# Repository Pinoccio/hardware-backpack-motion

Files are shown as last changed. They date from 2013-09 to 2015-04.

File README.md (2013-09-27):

motino-hardware-reference
===========================

Contained are the schematics, board layout, data sheets, and BOM for the Pinoccio motion shield, containing GPS, accelerometer, digital compass, and 3-axis gyro.

The board revisions are also marked as tags in the git repository, if you'd like to see a previous version.

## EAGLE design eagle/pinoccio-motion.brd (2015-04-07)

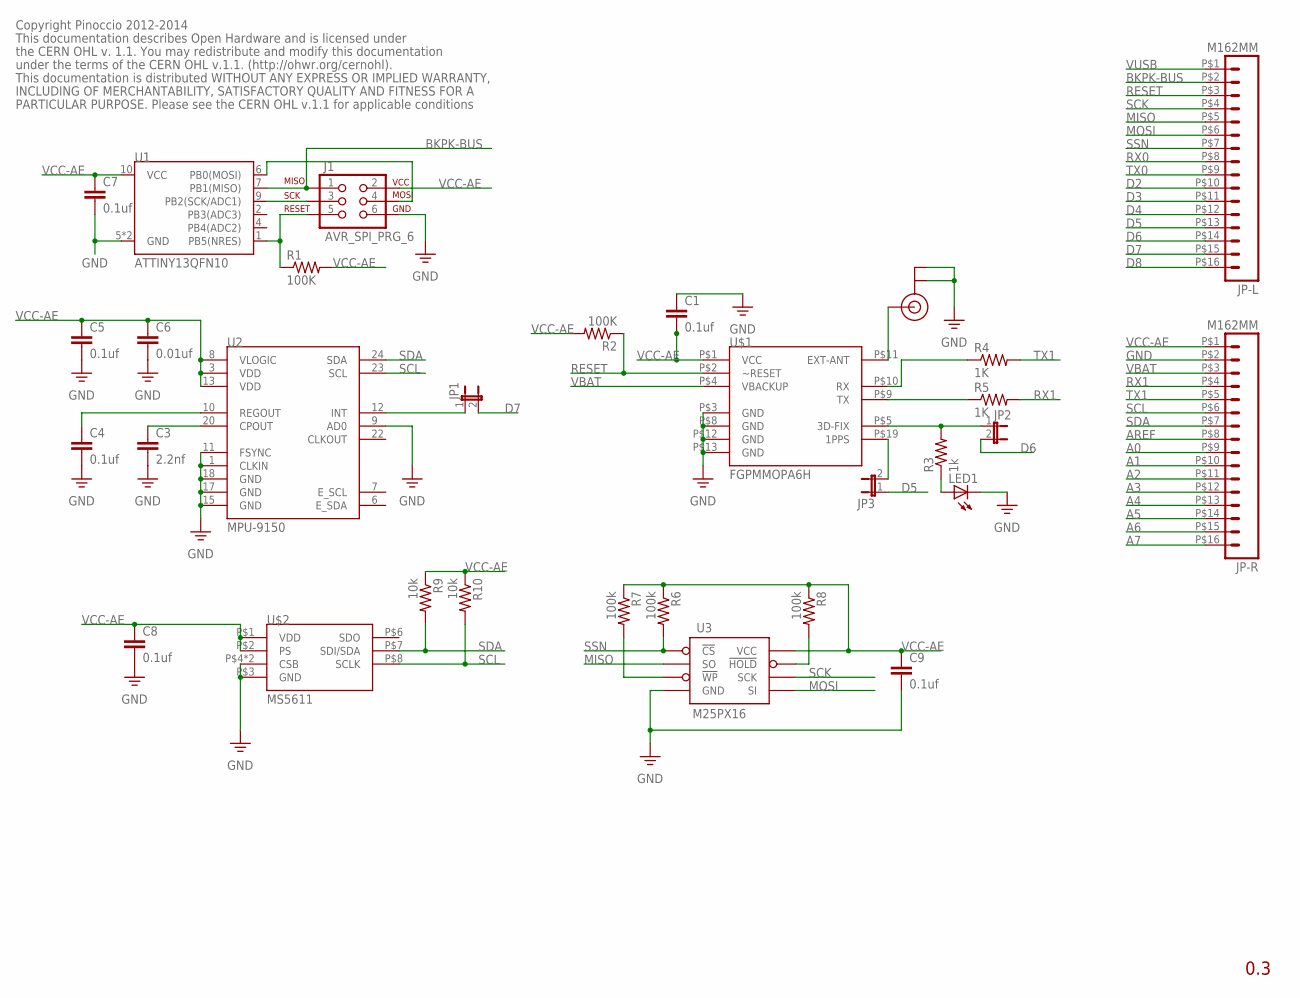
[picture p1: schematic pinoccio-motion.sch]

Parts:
C1, C4, C5, C7, C8, C9: 0.1uf; 0402-CAP
C3: 2.2nf; 0603-CAP
C6: 0.01uf; 0402-CAP
J1: AVR_SPI_PRG_6; 2X3-PAD
JP1, JP2, JP3: JUMPER-2SMD-NC; SJ_2S
JP-L: M162MM; 1X16_2MM
JP-R: M162MM; 1X16_2MM
LED1: LED0603; LED-0603
R1, R2: 100K; 0402-RES
R3: 1k; 0402-RES
R4, R5: 1K; 0402-RES
R6, R7, R8: 100k; 0402-RES
R9, R10: 10k; 0402-RES
U1: ATTINY13QFN10; QFN-10
U2: MPU-9150; QFN-24-NP
U3: M25PX16; SO8N
U$1: FGPMMOPA6H
U$2: MS5611
U$4: U.FL

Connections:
A0: JP-R.P$9 (9)
A1: JP-R.P$10 (10)
A2: JP-R.P$11 (11)
A3: JP-R.P$12 (12)
A4: JP-R.P$13 (13)
A5: JP-R.P$14 (14)
A6: JP-R.P$15 (15)
A7: JP-R.P$16 (16)
AREF: JP-R.P$8 (8)
BKPK-BUS: J1.1, JP-L.P$2 (2), U1.7 (PB1(MISO))
D2: JP-L.P$10 (10)
D3: JP-L.P$11 (11)
D4: JP-L.P$12 (12)
D5: JP3.1, JP-L.P$13 (13)
D6: JP2.2, JP-L.P$14 (14)
D7: JP1.2, JP-L.P$15 (15)
D8: JP-L.P$16 (16)
GND: C1.1, C3.2, C4.2, C5.2, C6.2, C7.2, C8.2, C9.2, J1.6, JP-R.P$2 (2), LED1.C, U1.5 (GND), U1.EP (GND), U2.1 (CLKIN), U2.9 (AD0), U2.11 (FSYNC), U2.15 (GND), U2.17 (GND), U2.18 (GND), U3.4 (GND), U$1.P$3 (GND), U$1.P$8 (GND), U$1.P$12 (GND), U$1.P$13 (GND), U$2.P$3 (GND), U$2.P$4 (CSB), U$2.P$5 (CSB), U$4.P$1 (GND), U$4.P$2 (GND)
MISO: JP-L.P$5 (5), U3.2 (SO)
MOSI: JP-L.P$6 (6), U3.5 (SI)
unnamed: J1.4, U1.6 (PB0(MOSI))
unnamed: R4.1, U$1.P$10 (RX)
unnamed: J1.3, U1.9 (PB2(SCK/ADC1))
unnamed: J1.5, R1.1, U1.1 (PB5(NRES))
unnamed: U$1.P$11 (EXT-ANT), U$4.P$3 (SIGNAL)
unnamed: R5.1, U$1.P$9 (TX)
unnamed: JP1.1, U2.12 (INT)
unnamed: C3.1, U2.20 (CPOUT)
unnamed: JP2.1, R3.2, U$1.P$5 (3D-FIX)
unnamed: JP3.2, U$1.P$19 (1PPS)
unnamed: C4.1, U2.10 (REGOUT)
unnamed: R7.2, U3.3 (!WP)
unnamed: R8.2, U3.7 (!HOLD)
unnamed: LED1.A, R3.1
RESET: JP-L.P$3 (3), R2.1, U$1.P$2 (~RESET)
RX0: JP-L.P$8 (8)
RX1: JP-R.P$4 (4), R5.2
SCK: JP-L.P$4 (4), U3.6 (SCK)
SCL: JP-R.P$6 (6), R10.2, U2.23 (SCL), U$2.P$8 (SCLK)
SDA: JP-R.P$7 (7), R9.2, U2.24 (SDA), U$2.P$7 (SDI/SDA)
SSN: JP-L.P$7 (7), R6.2, U3.1 (!CS)
TX0: JP-L.P$9 (9)
TX1: JP-R.P$5 (5), R4.2
VBAT: JP-R.P$3 (3), U$1.P$4 (VBACKUP)
VCC-AE: C1.2, C5.1, C6.1, C7.1, C8.1, C9.1, J1.2, JP-R.P$1 (1), R1.2, R2.2, R6.1, R7.1, R8.1, R9.1, R10.1, U1.10 (VCC), U2.3 (VDD), U2.8 (VLOGIC), U2.13 (VDD), U3.8 (VCC), U$1.P$1 (VCC), U$2.P$1 (VDD), U$2.P$2 (PS)
VUSB: JP-L.P$1 (1)

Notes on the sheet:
0.3
Copyright Pinoccio 2012-2014
This documentation describes Open Hardware and is licensed under
the CERN OHL v. 1.1. You may redistribute and modify this documentation
under the terms of the CERN OHL v.1.1. (http://ohwr.org/cernohl).
This documentation is distributed WITHOUT ANY EXPRESS OR IMPLIED WARRANTY,
INCLUDING OF MERCHANTABILITY, SATISFACTORY QUALITY AND FITNESS FOR A
PARTICULAR PURPOSE. Please see the CERN OHL v.1.1 for applicable conditions

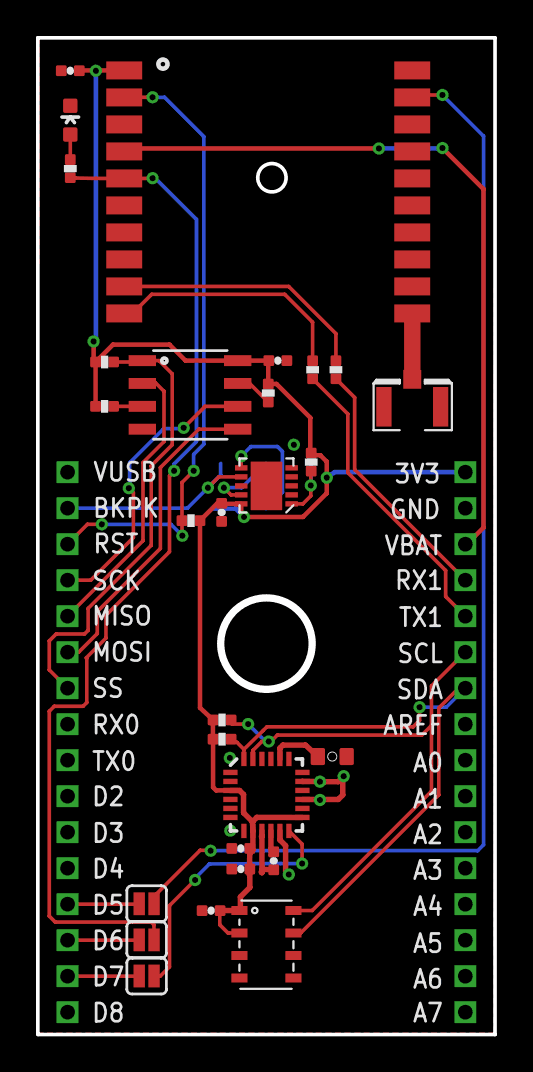
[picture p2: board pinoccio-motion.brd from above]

Board: 2 copper layers, 25.4 x 55.4 mm, 31 parts (1 on the bottom side), 30 nets.

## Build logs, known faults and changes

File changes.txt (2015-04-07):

- v0.3 - 2013-09-19
- Move MPU-9150 INT pin to D7 for hardware interrupt
- Add 0.1µF cap to VCC input of GPS unit

------------------------------------------------------------------------
- v0.2 - 2013-07-10
- Add serial flash storage
- Add GPS antenna port

------------------------------------------------------------------------
- v0.1 - 2013-02-10
- Contributors
  - Pinoccio Team
------------------------------------------------------------------------
- Initial release

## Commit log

2013-09-27 updated motion to v0.1
    [pinoccio-motion.brd, pinoccio-motion.sch, pinoccio-proto.brd]
2015-04-07 v0.2 fixes
    [pinoccio-motion.brd, pinoccio-motion.sch]

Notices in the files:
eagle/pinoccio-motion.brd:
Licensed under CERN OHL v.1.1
